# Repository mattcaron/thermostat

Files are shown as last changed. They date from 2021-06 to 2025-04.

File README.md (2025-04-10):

# The super awesome thermostat

## Introduction

Let's face it - all these thermostat products you can buy today are any or many of:

1. stupid expensive,
1. flawed in some way
1. don't do exactly what you want (see above)
1. aren't hackable
1. sell your data to some huge company

Let's address that, shall we?

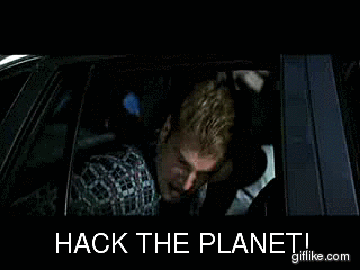
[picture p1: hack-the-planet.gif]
HACK THE PLANET!!!


## Getting started

Clone this as follows:

```shell
git clone --recursive https://github.com/mattcaron/thermostat.git
```

This will get this repo and all the submodules uses (such as the Espressif repositories).

## Components

### Thermometer puck sensors

This is intended to be pretty turnkey. Build it, flash it, configure it,
stick it on the wall. It will send COAP messages to your server (see below)
which you then consume in NodeRED (also below) and make it do what you want.

**Status:** Completed, apart from TODOs. See the `sensors` subdirectory.

**Roadmap:**

1. Hardware selection: Completed
1. Firmware: Done (v2.0.0)
   1. Console: Done
   1. Config: Done
   1. OneWire to DS18B20: Done
   1. WiFi refactor: Done
   1. ~~MQTT: Done~~
      1. Replace with COAP: Done
   1. Power saving deep sleep: Done
1. Wiring diagram: Done
   - See [./sensors/wiring_instructions/wiring_instructions.md](./sensors/wiring_instructions/wiring_instructions.md)
1. Case design: Done
   - See `./enclosures/sensor*.stl`
   - These are generated from [./enclosures/sensor_puck.scad](./enclosures/sensor_puck.scad)

**TODO:**

(May never be implemented)

1. Implement CLI command completion hinting (see iperf example code).
1. CoAP DTLS
   1. The ESP8266 library supports it.
   1. The NodeRED node-red-contrib-coap doesn't.
   1. A proxy would likely work here.
1. IPv6 support for static IPs.

**Notes:**

1. **MAKE SURE YOU DO NOT CONNECT TO BOTH USB AND BATTERIES**. Seriously - the
   batteries are going to push somewhere between 3V and 4.5V and the USB is
   going to push 5V so it's likely to try to charge the batteries and that is
   probably not going to end well. Remove the batteries, *then* plug in USB.
   This should be a pretty easy mistake to avoid since this assumes a battery
   holder with screw holes behind the batteries - in order to upgrade firmware,
   you need to take the whole thing apart, and the first step to doing that is
   pulling out the batteries.
1. When you flash the firmware:
   1. The config is retained, as it is stored in a different flash partition
      than the firmware.
   1. You need to pull out the jumper wire between D0 and RST. This connection
      is necessary for deep sleep, but messes up the automatic reset circuit
      for flashing.
   1. If the delay between plugging in USB and starting the flashing process is
      too long, the board will go to deep sleep (from which it will not actually
      wake - see above) and not flash properly. If the flashing fails, hit the
      reset button, then start the flash process again.
1. I originally implemented this using 9 bit DS18B20 resolution, but the 0.5 C
   resolution was lacking. After profiling where we were spending our time, the
   overwhelming majority of it was spent waiting to bring ip WiFi, get an IP,
   etc. Therefore, it cost us very little in terms of power to kick off a full
   resolution (12 bit) conversion, giving us 0.0625C resolution.

**Known bugs:**

(May never be implemented)

1. If you save the config at the wrong time, it can try to take down WiFi when
   it is already being brought down so the unit can go to sleep. This causes an
   ESP_ERROR_CHECK to fail (because you can't bring down something that's
   already being brought down), causing a panic reboot. Eventually, I'll get
   around to modifying it so as to check for that specific error condition and
   ignore it. Note that, when this happens, the config is saved before it
   reboots, so it's not like you lose anything. Further, this is not likely to
   occur outside of initial setup - hence why I haven't bothered to
   fix it.

#### BOM

Example links are provided for clarity, in cases where the hardware is uncommon.

##### Hardware list

You will need one of each of these items for each "puck".

1. LOLIN D1 Mini Board
   - I had used a knockoff board for the previous generation, but the LDO
     regulator used was complete garbage (quiescent current measured in
     milliAmps, not microAmps) and that led to dramatically reduced battery life.
   - <https://www.wemos.cc/en/latest/d1/d1_mini.html>
1. 3 AAA battery holder with leads
   - <https://www.amazon.com/gp/product/B0156V1JGQ>
1. DS18B20 - Get the actual Maxim one.
   - I used the genuine article here, because I tried a couple of knockoffs and
    they lacked the ability to save configuration and were less precise than the
    actual Maxim product.
      - The above is accurate, but if you run it at 12 bit resolution (the
        default), it doesn't matter, and a generic knockoff will probably work
        fine. Your mileage may vary. See `sensors/main/temperature.c` and set
        `SENSOR_CONFIG_REG_VALUE` and `MEASUREMENT_DELAY_MS` accordingly.
   - <https://www.mouser.com/ProductDetail/?qs=7H2Jq%252ByxpJKpIDCbiq4lfg%3D%3D>
1. Wire of appropriate gauge - one spool each of red and black (for power and
   ground) and another for signal (orange, yellow, blue, etc.) in 22 AWD should
   work fine here.
1. Heat shrink tubing for the above - you're going to be soldering to the ends
   of the DS18B20 sensor and you'll want to heat shrink over them to ensure you
   don't get any shorts.
   - Alternatively, if you want to do slightly less soldering, you could find a
     3 pin pigtail lead with breadboard (2.54mm) pin spacing, plug the DS18B20's
     into the plug end and solder the other end to the ESP board. But, wire is
     cheaper and I rather enjoy soldering - it lets me catch up on my Oak
     Island. Your call.

#### Enclosure

The enclosure is meant to be 3D printed. See the `enclosures` subdirectory. The
files are all generated from a single SCAD file. If you want to re-render or
modify them, feel free to do so. OpenSCAD is what I use.

However, this is not strictly necessary, because I've already exported the 3
pieces as `.stl`s. They are meant to print flat, without supports, in the
orientation in which they are presented, on an FDM printer. They should print
fine in any common 3D printing material. PLA will probably work fine, given the
limited environmental effects to which they will be exposed. I used PETG, my
rationale being that it should survive the temperature fluctuations and UV
exposure a little better than PLA, but mainly because I wanted an excuse to get
PETG printing dialed in on my printer - it's still pretty stringy, but vastly
improved versus the beginning of the project.

In addition to whatever filament you will be using, you will also need
sufficient self-tapping screws to fasten the battery holder to the lid of the
enclosure - with the screws passing through the divider. I used M3 x 12mm wood
screws, as that was the head profile for which my battery holders were made.

Please note that the holes in both the lid and divider are merely intended to be
pilot holes. Since I do not know what size screw you plan to use, I cannot
ensure the correct dimension. As such, 2 drill bits will be needed.

The first must be larger than your screw and, ideally, the same diameter as the
holes in the battery holder. The goal here is to have the screw threads *not*
engage with the plastic in either the divider or the battery holder.

The second should be the diameter of your screws sans threads - the idea being
that the self-tapping screws will cut walls into the printed standoff parts of
the lid.

Given that you will be removing some material from the walls of the standoffs so
the screws do not crack the plastic, it is necessary to ensure thick enough
walls for them to not be to thin. I recommend a minimum of 2mm thick walls when
printing the lid.

The divider is intended to ensure that the board and thermostat stay in
position, with the CPU located under the upper vent and the DS18B20 positioned
just above the lower vent. The idea here is that the CPU will heat up and the
warm air will vent out the top. Ambient air will be drawn in and over the
temperature sensor, theoretically giving a more accurate reading (and surely
more accurate than if the DS18B20 was on above the CPU, with the CPU sitting
there baking it). The horizontal protrusions into which one screws the battery
case and divider are intended to serve as a heat brake as well.

Finally, note that there are no clips on this assembly, as it is meant to be
stuck to the wall with some variety of double stick tape (I like the 3M command
strips). As such, the base is stuck to the wall and the lid, batteries, board,
etc. just pull straight off. They are held in place by gravity and a small
amount of friction. The fit is snug, but not tight. As such, mounting it on the
ceiling is not advised, as it will almost certainly work loose from the
vibrations of people walking through the building and invariably land on your
cat's head. (Don't say I didn't warn you.)

### Base station

This is not intended to be a plug and go - users are expected
to program this for their specific home layout. The idea is that, if your
sensors all report the temperature, you can define what happens using
NodeRED. For the unfamiliar, NodeRED is a programming language using drag and
drop logic blocks, with the ability to program custom logic blocks in
JavaScript. As such, it should be pretty approachable to the novice
programmer.

**Status:** Done

1. Hardware selection: Completed, see below.
   - I'm not going to do a schematic for this because it's very application
     specific.
   - In short:
     1. Get an RPi
     1. Get an appropriate number of relay boards.
     1. Wire them all together.
     1. Connect your HVAC kit.
     1. Write a NodeRed program to control it all.
1. Enclosure: Done.
   - It's slotted for a slide-in cover. I plan to make one out of
   clear acrylic, just a simple score and snap.
   - See `./enclosures/controller_base.stl` for a render.
   - This is generated from
     [./enclosures/controller_base.scad](./enclosures/controller_base.scad),
     which will almost certainly require modification unless your set up is
     exactly the same as mine.
1. Firmware: Done
   1. RPi base uses RPiOS + NodeRed + some plugins
   1. Firmware is a NodeRed program - see `controller/controller.json`.

#### BOM

Example links are provided for clarity, in cases where the hardware is uncommon.

##### Hardware list

1. Raspberry Pi 3B+
   - RPi4 would likely work with minimal modification to these
   instructions.
1. SD card
   - 32GB is fine.
1. RPi screw terminal expansion board with status LEDs
   - <https://www.amazon.com/GeeekPi-Raspberry-Terminal-Breakout-Expansion/dp/B08GKSF1MD>
   - Not strictly necessary, as one can just wire directly to the header block,
     but screw terminals ensure positive connections that won't pull out on you.
1. Some solid state relay modules
   - I bought one of
     <https://www.amazon.com/SainSmart-Channel-Duemilanove-MEGA2560-MEGA1280/dp/B00ZZVQR5Q>
     for each of my zones.
   - You can get ones with more or fewer relays as needed.
   - Note that you will need at least 3 for a common setup:
     - Fan
     - Cooling
     - Heating

     More advanced setups (for example, multistage heating and cooling) will
     require more contacts.
   - You can use mechanical relays if you like, as they are cheaper. However,
     they draw more current and will (eventually) mechanically wear out. The RPi
     3B+ GPIOs are spec-ed at max 16mA per channel, with 50mA aggregate.
       - This article from arrow explains it well:
         <https://www.arrow.com/en/research-and-events/articles/crydom-solid-state-relays-vs-electromechanical-relays>
       - Using some commonly available numbers as an example, the stated typical
         current draw for a commonly used electromechanical relay was 70mA,
         wheras it was 10mA for the SSR (though in both cases, actual measured
         current draw in situ was about an order of magnitude less).
   - Note that there is a bit of a cheat here - I assume that only one contact
     will be closed at any given time per zone - that is, only one of fan, heat,
     or cool. If this is not true, and you have enough zones, you can exceed the
     overall current rating for the board. For example, if we turn on fan and
     heat for 3 zones at the stated 10mA power consumption, we will end up at
     60mA, which is more than the allowed aggregate across all GPIO contacts.

- 24VAC to 5V buck converter
  - I used
      <https://www.amazon.com/SMAKN%C2%AE-Converter-Voltage-Supply-Waterproof/dp/B00RE6QN4U>
      soldered to the power and ground pins of a USB wire.
  - The logic here is that we can power it from the 24VAC that's readily
      available at the equipment and won't have to use an additional power brick.

##### Misc supplies and equipment

1. Stranded wire for connecting screw terminals to relays.
1. Tools - strippers, small screwdrivers, etc.
1. Some lengths of furnace wire for connecting to HVAC equipment or a zone
   controller.

## Battery notes

1. As mentioned above, use a board with a good LDO regulator. We already put the
   board into deep sleep, but the power regulator consumes power at idle and the
   less it consumes, the longer the battery will last.
2. Enable access point caching (`config set cache_ap Y`). This will cut down the
   amount of time it takes to wake from deep sleep and get wifi up, saving time
   and power. If it fails to associate with the last AP, it will fall back to
   the standard process.
3. Disable DHCP (`config set use_dhcp N`) and then set a static IP and netmask
   (`config set ip_addr XXX.XXX.XXX.XXX` `config set netmask YYY.YYY.YYY.YYY`).
   This will save several exchanges over WiFi, and those tend to consume a lot
   of power (especially while transmitting). Also saves several seconds of runtime.
4. Use the static IP of your base station in the coap URL (`config set uri
   coap://ZZZ.ZZZ.ZZZ.ZZZ/whatever`). This saves a DNS lookup which, again,
   takes time and power. Note that this only works **if you know it won't
   change**. If it might change, use its hostname.

## Security notes

### WiFi

Connecting to networks with crappy (or no) security is allowed. It's your
funeral.

### SSL

#### Sensor (COAP+DTLS)

Not yet implemented, and should be. The problem is, `node-red-contrib-coap`
doesn't support DTLS, so I need to implement some sort of proxy. Big TODO that I
actually intend to do... but haven't.

In the interim, throwing a slug on the end of the target COAP URL so people
can't poison your sensor data may help. It's a little security by obscurity, but
better than nothing. I added a -12345 in my example. I know, I know, it's the
kind of thing an idiot would have on his luggage, but it's not what I'm actually
using in production.

#### NodeRED / Webserver

This is just using the default selfsigned cert that's generated when Apache is
installed.

## License

Broadly speaking, this code is licensed under the 3-Clause BSD license. However,
it incorporates various third party modules that have their own licenses, in
which case those licenses apply. If there is ever a conflict (for example, a
derived work), then the terms of that license have precedence. See the LICENSE
file for more details.

## FAQ

### **Y U NO ZIGBEE?**

Because I have WiFi coverage all over my house, and the cost is about the same.
I will grant you that battery life would be better with Zigbee, but that's not
the only consideration in play here.

### **What's all this about your data and huge coporations?**

Maybe it's because I don't like being the product. Maybe I just read too much
cyberpunk. Maybe I just am a little paranoid. Or maybe I'm just a control freak.
Take your best guess.

### **But, half the links are to Amazon!**

Yeah, I'm a hypocrite too, what's your point?

### **How long is the battery life?**

In v1, it was about a month. This was using the old MQTT implementation, DHCP,
not caching the AP, and connecting to the base via hostname.

In v2, using COAP and all the techniques listed up in "Battery notes", a set of
3 2000mAh batteries last about 2.5 months. 2400mAh batteries push you over 3
months. Note that these need to *actually* be performing at their rated
capacities - I've gotten a lot of batteries that said 2400 or higher on the
nameplate, and they only test out to about 2000mAh.

## Acknowledgements

1. I totally cribbed battery saving techniques from
   <https://blog.sarine.nl/2020/01/01/1-year-sensor.html>
1. The above linked to <https://www.bakke.online/index.php/2017/06/24/esp8266-wifi-power-reduction-avoiding-network-scan/>
 which I also incorporated (though I just wrote to NVS, not RTC.)

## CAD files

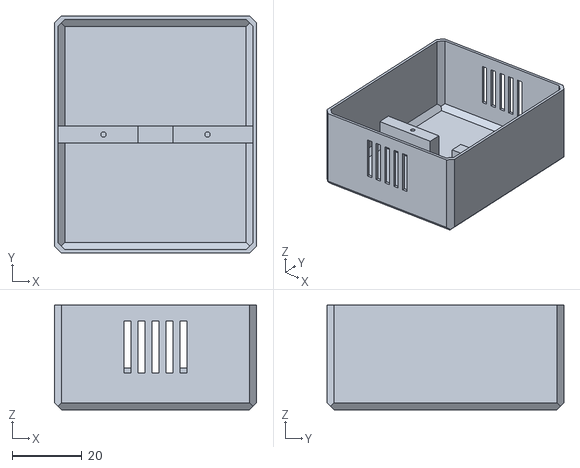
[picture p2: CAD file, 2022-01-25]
enclosures/sensor_puck_lid.stl
58.0 x 68.0 x 30.0

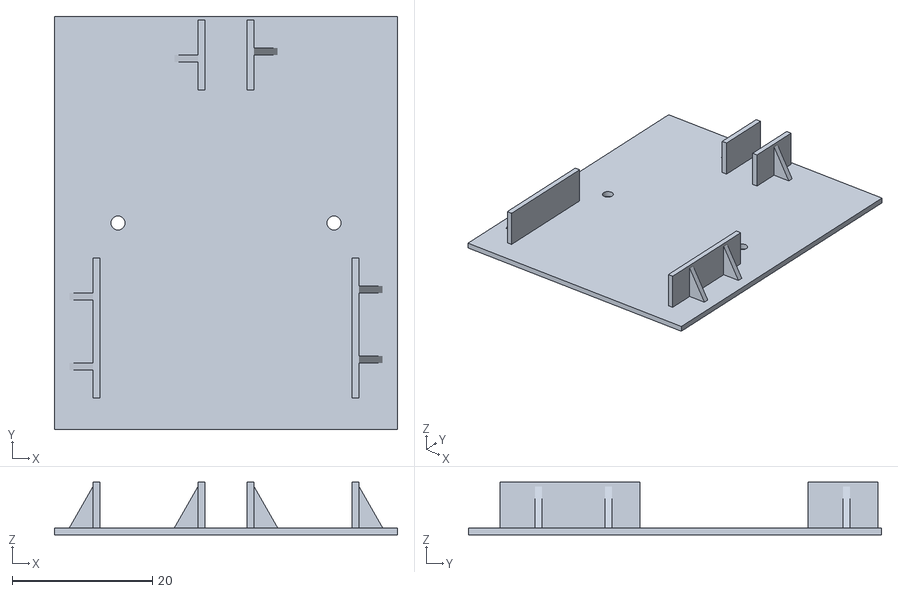
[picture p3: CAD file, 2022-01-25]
enclosures/sensor_puck_divider.stl
49.0 x 59.0 x 7.50

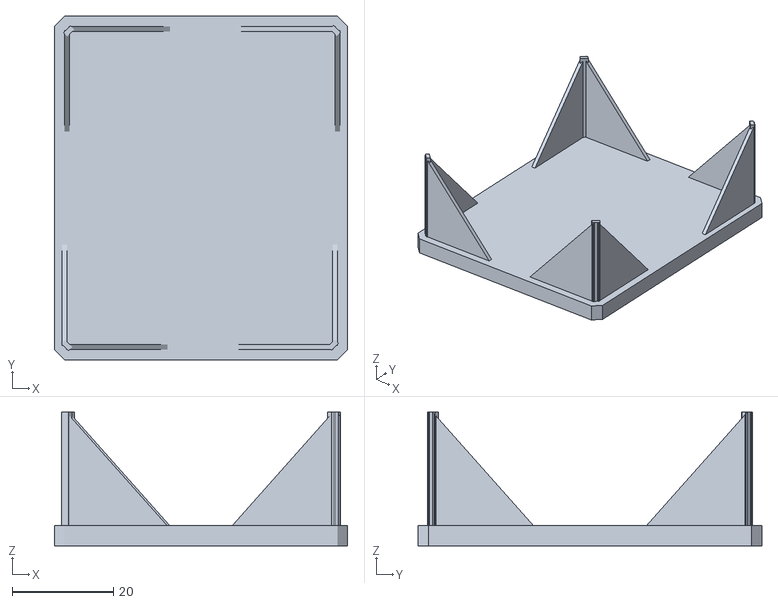
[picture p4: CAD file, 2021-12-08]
enclosures/sensor_puck_base.stl
58.0 x 68.0 x 26.5

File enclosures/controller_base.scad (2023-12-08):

include <triangles.scad>;

// Dimensions are in mm

// Fragment count. Use this many fragments to make a circle.
$fn = 360;

base_length = 180;
base_width = 180;
base_thickness = 5;
// cover holder height - this is the RPI height plus the 10mm standoffs, plus a bit
base_height = 60;

// thickness of lexan cover
lexan_thickness = 4;

// thickness of "stands" to support the above lexan cover
cover_support_thickness = 3;

// how much the angle should come out into the main base
cover_support_reinforcement = 15;

// all our standoffs are the same size
standoff_height = 10;
standoff_diameter = 5;

// screws. The hole should be large enough to not engage the threads.
screw_hole_diameter = 3;
screw_head_diameter = 5;
screw_hole_height = 1000; // more or less infinitely high.
// min thickness of the board for the screws to actually be 
// held by
board_screw_thickness = 1;

// larger screws for power converter. These are coarse thread
// self-tapping screws that are just screwed into the backer.
// This should be small enough to enage the threads,
large_screw_hole_diameter = 3.5;

// extra standoffs for the converter, because the screws I'm
// using are 13mm long and 3mm wings and a 5mm base means they would
// stick out the back. So make a 10mm standoff, measured from the bottom
// of the base (not elevated) to screw the screws into
large_screw_standoff_height = 10;

// anchor screws for mounting to the wall. This should be
// large enough to not engage the threads.
anchor_screw_hole_diameter = 6;

// SSR board volume with standoffs
module makeSSRBoard() {
    length = 73;
    width = 62;
    height = 25;
    
    union() {
        // base board volume
        cube([length, width, height]);
        
        // standoffs
        translate([5, 5, -standoff_height]) {
            cylinder(d = standoff_diameter, h = standoff_height);
        }
        
        translate([5, 56, -standoff_height]) {
            cylinder(d = standoff_diameter, h = standoff_height);
        }
        
        translate([67, 5, -standoff_height]) {
            cylinder(d = standoff_diameter, h = standoff_height);
        }
        
        translate([67, 56, -standoff_height]) {
            cylinder(d = standoff_diameter, h = standoff_height);
        }
    }
}

// this is a positive add that needs to be differenced out by whatever calls it.
module makeSSRBoardHoles() {
    // shoot some holes in it for the screws - they are infinitely tall so we can see them at the top.

    // shafts
    translate([5, 5, -screw_hole_height/2]) {
        cylinder(d = screw_hole_diameter, h = screw_hole_height);
    }
        
    translate([5, 56, -screw_hole_height/2]) {
        cylinder(d = screw_hole_diameter, h = screw_hole_height);
    }
        
    translate([67, 5, -screw_hole_height/2]) {
        cylinder(d = screw_hole_diameter, h = screw_hole_height);
    }
     
    translate([67, 56, -screw_hole_height/2]) {
        cylinder(d = screw_hole_diameter, h = screw_hole_height);
    }
    
    // heads
    translate([5, 5, -(base_thickness + board_screw_thickness + standoff_height)]) {
        cylinder(d = screw_head_diameter, h = base_thickness);
    }
    
    translate([5, 56, -(base_thickness + board_screw_thickness + standoff_height)]) {
        cylinder(d = screw_head_diameter, h = base_thickness);
    }
    
    translate([67, 5, -(base_thickness + board_screw_thickness + standoff_height)]) {
        cylinder(d = screw_head_diameter, h = base_thickness);
    }
    
    translate([67, 56, -(base_thickness + board_screw_thickness + standoff_height)]) {
        cylinder(d = screw_head_diameter, h = base_thickness);
    }
}

module makeRPI() {
    length = 88;
    width = 60;
    height = 41; // includes 15mm of space to plug into header pins and route wires
         
    union() {
        // base board volume
        cube([length, width, height]);
        
        // standoffs
        translate([3.5, 6.5, -standoff_height]) {
            cylinder(d = standoff_diameter, h = standoff_height);
        }

        translate([3.5, 55.5, -standoff_height]) {
            cylinder(d = standoff_diameter, h = standoff_height);
        }

        translate([61.5, 6.5, -standoff_height]) {
            cylinder(d = standoff_diameter, h = standoff_height);
        }

        translate([61.5, 55.5, -standoff_height]) {
            cylinder(d = standoff_diameter, h = standoff_height);
        }
    }
}

// this is a positive add that needs to be differenced out by whatever calls it.
module makeRPIBoardHoles() {
    // shoot some holes in it for the screws - they are infinitely tall so we can see them at the top.

    // shafts
    translate([3.5, 6.5, -screw_hole_height/2]) {
        cylinder(d = screw_hole_diameter, h = screw_hole_height);
    }
        
    translate([3.5, 55.5, -screw_hole_height/2]) {
        cylinder(d = screw_hole_diameter, h = screw_hole_height);
    }
        
    translate([61.5, 6.5, -screw_hole_height/2]) {
        cylinder(d = screw_hole_diameter, h = screw_hole_height);
    }
     
    translate([61.5, 55.5, -screw_hole_height/2]) {
        cylinder(d = screw_hole_diameter, h = screw_hole_height);
    }
    
    // heads
    translate([3.5, 6.5, -(base_thickness + board_screw_thickness + standoff_height)]) {
        cylinder(d = screw_head_diameter, h = base_thickness);
    }
    
    translate([3.5, 55.5, -(base_thickness + board_screw_thickness + standoff_height)]) {
        cylinder(d = screw_head_diameter, h = base_thickness);
    }
    
    translate([61.5, 6.5, -(base_thickness + board_screw_thickness + standoff_height)]) {
        cylinder(d = screw_head_diameter, h = base_thickness);
    }
    
    translate([61.5, 55.5, -(base_thickness + board_screw_thickness + standoff_height)]) {
        cylinder(d = screw_head_diameter, h = base_thickness);
    }
}

module makeConverter() {
    length = 46.5;
    width = 31.5;
    height = 18;
      
    // no standoffs, but it has "wings" with U cutouts
    // for the screws
    
    wing_width = 13;
    wing_length = 9;
    wing_height = 3.5;
    
    cutout_width = 4;
    cutout_length = 7;
    
    union() {
        // base board volume
        cube([length, width, height]);
        
        // wings
        translate([length, width/2 - wing_width/2, 0]) {
            difference() {
                cube([wing_length, wing_width, wing_height]);
                translate([wing_length - cutout_length + 0.1,
                           wing_width/2 - cutout_width/2,
                           -wing_height/2]) {
                    cube([cutout_length, cutout_width, wing_height * 2]);
                }
            }
        }
        
        translate([-wing_length, width/2 - wing_width/2, 0]) {
            difference() {
                cube([wing_length, wing_width, wing_height]);
                translate([-(wing_length - cutout_length - 1.9),
                           wing_width/2 - cutout_width/2,
                           -wing_height/2]) {
                    cube([cutout_length, cutout_width, wing_height * 2]);
                }
            }
        }
    }
}

// this is a positive add that needs to be differenced out by whatever calls it.
module makeConverterBoardHoles() {
    
    // shafts
    translate([-5, 15.75, -screw_hole_height/2]) {
        cylinder(d = large_screw_hole_diameter, h = screw_hole_height);
    }
        
    translate([52, 15.75, -screw_hole_height/2]) {
        cylinder(d = large_screw_hole_diameter, h = screw_hole_height);
    }
}

module make18B20Board() {
    length = 24.5;
    width = 21;
    height = 14.5; // includes 15mm of space to plug into header pins and route wires
    
    union() {
        // base board volume
        cube([length, width, height]);
        
        // standoffs
        translate([2.5, 2.5, -standoff_height]) {
            cylinder(d = standoff_diameter, h = base_thickness);
        }

        translate([2.5, 18, -standoff_height]) {
            cylinder(d = standoff_diameter, h = base_thickness);
        }
    }
    
}

// this is a positive add that needs to be differenced out by whatever calls it.
module make18B20BoardHoles() {
    
    // shafts
    translate([2.5, 2.5, -screw_hole_height/2]) {
        cylinder(d = screw_hole_diameter, h = screw_hole_height);
    }
        
    translate([2.5, 18, -screw_hole_height/2]) {
        cylinder(d = screw_hole_diameter, h = screw_hole_height);
    }
    
    // heads
    translate([2.5, 2.5, -(base_thickness + board_screw_thickness + standoff_height)]) {
        cylinder(d = screw_head_diameter, h = base_thickness);
    }
    
    translate([2.5, 18, -(base_thickness + board_screw_thickness + standoff_height)]) {
        cylinder(d = screw_head_diameter, h = base_thickness);
    }
}
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

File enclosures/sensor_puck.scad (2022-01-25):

include <Chamfers-for-OpenSCAD/Chamfer.scad>;
include <triangles.scad>;

// Dimensions are in mm

// Fragment count. Use this many fragments to make a circle.
$fn = 360;
delta = 0.1;

// this is the gap between the "fingers" that hold the lid on,
// and the lid itself. We want this as tight as possible, so it
// doesn't fall off, but not so tight that you rip the sensor off
// the wall trying to pull it off.
wall_gap = 0.5;

enclosure_height = 70;
enclosure_length = 60;
enclosure_lid_depth = 30;
enclosure_base_depth = 4;
enclosure_wall_thickness = 2;
enclosure_divider_thickness = 1;

// there is this much subtracted from each edge of the divider
// so that it fits inside.
enclosure_divider_delta = enclosure_wall_thickness+wall_gap+3;

hole_spacing = 26.85;

// showAssembledUnit();

showItemsForPrinting();

// Render the unit, with internal components, assembled in situ.
// Comment out bits here to see how things are and do development.
module showAssembledUnit() {
    makeComponents();
    makeEnclosureLid();
    makeEnclosureBase();
    makeEnclosureDivider();
}

module showItemsForPrinting() {
/*
    translate([0,0,14]) {
        rotate([90,-90,0]) {
            makeEnclosureBase();
        }
    }
*/

    translate([0,0,20]) {
        rotate([90,90,0]) {
            makeEnclosureLid();
        }
    }

/*
    translate([0,0,-7]) {
        rotate([90,-90,0]) {
            makeEnclosureDivider();
        }
    }
*/
}

// Make the lid of the enclosure, which contains the
// components.
module makeEnclosureLid() {
    hole_diameter = 1.5;
    
    difference() {
        // basic hollow chamfered box
        translate([-10,
                   (-enclosure_length/2)+1,
                   (-enclosure_height/2)+1]) {
    
            difference() {
                chamferCube([enclosure_lid_depth,
                            enclosure_length-enclosure_wall_thickness,
                            enclosure_height-enclosure_wall_thickness],
                            ch=2,
                            chamfers=[[1, 1, 1, 1],
                                    [0, 0, 1, 1],
                                    [0, 1, 1, 0]]);
    
                translate([-enclosure_wall_thickness,
                            enclosure_wall_thickness/2,
                            enclosure_wall_thickness/2]) {
                    chamferCube([enclosure_lid_depth,
                                enclosure_length-
                                    enclosure_wall_thickness*2,
                                enclosure_height-
                                    enclosure_wall_thickness*2],
                                ch=2,
                                chamfers=[[1, 1, 1, 1],
                                        [0, 0, 1, 1],
                                        [0, 1, 1, 0]]);
                            }
                    }
            }
           
            // vents in box
            translate([enclosure_wall_thickness,
                       0,
                       -(enclosure_height/2-delta)]) {
                cube([enclosure_lid_depth/2,2,4], center=true);
            }
            translate([enclosure_wall_thickness,
                       4,
                       -(enclosure_height/2-delta)]) {
                cube([enclosure_lid_depth/2,2,4], center=true);
            }
            translate([enclosure_wall_thickness,
                       8,
                       -(enclosure_height/2-delta)]) {
                cube([enclosure_lid_depth/2,2,4], center=true);
            }
            translate([enclosure_wall_thickness,
                       -4,
                       -(enclosure_height/2-delta)]) {
                cube([enclosure_lid_depth/2,2,4], center=true);
            }
            translate([enclosure_wall_thickness,
                       -8,
                       -(enclosure_height/2-delta)]) {
                cube([enclosure_lid_depth/2,2,4], center=true);
            }
            translate([enclosure_wall_thickness,
                       0,
                       enclosure_height/2-delta]) {
                cube([enclosure_lid_depth/2,2,4], center=true);
            }
            translate([enclosure_wall_thickness,
                       4,
                       enclosure_height/2-delta]) {
                cube([enclosure_lid_depth/2,2,4], center=true);
            }
            translate([enclosure_wall_thickness,
                       8,
                       enclosure_height/2-delta]) {
                cube([enclosure_lid_depth/2,2,4], center=true);
            }
            translate([enclosure_wall_thickness,
                       -4,
                       enclosure_height/2-delta]) {
                cube([enclosure_lid_depth/2,2,4], center=true);
            }
            translate([enclosure_wall_thickness,
                       -8,
                       enclosure_height/2-delta]) {
                cube([enclosure_lid_depth/2,2,4], center=true);
            }            

    }
  
    
    // standoffs to which we screw the battery box
    difference() {
        translate([13, 0, 0]) {
            cube([enclosure_lid_depth - 20,
                  enclosure_length - enclosure_wall_thickness,
                  5],
                  center=true);
        }
        // holes
        translate([-10,
                   -(hole_spacing/2+hole_diameter),
                   0]) {
                 rotate([90,0,90]) {
                    cylinder(d=hole_diameter, h=20);
                 }
        }
        translate([-10,
                  hole_spacing/2+hole_diameter,
                  0]) {
                rotate([90,0,90]) {
                    cylinder(d=hole_diameter, h=20);
                 }
        }
        // wiring chase
        translate([10,0,0]) {
            cube([enclosure_lid_depth + delta - 15,10,12],center=true);
        }
    }
}

// Make the divider which separates the battery holder from
// the temperature sensor and PCB
module makeEnclosureDivider() {
    hole_diameter = 2;
    translate([7.8,0,0]) {
        difference() {
            cube([enclosure_divider_thickness,
                  enclosure_length - (enclosure_divider_delta * 2),
                  enclosure_height - (enclosure_divider_delta * 2)],
                  center=true);
            
            // holes
            translate([-10, -(hole_spacing/2+hole_diameter), 0]) {
                        rotate([90,0,90]) {
                        cylinder(d=hole_diameter, h=20);
                }
            }
            translate([-10, hole_spacing/2+hole_diameter, 0]) {
                rotate([90,0,90]) {
                    cylinder(d=hole_diameter, h=20);
                }
            }
        }
        
        // add in some clips
        
        // PCB clips, to prevent lateral movement.
        // Vertical movement is limited by the standoffs and lid
        
        // left side
        makeLeftSidePCBDividerClip();
        
        translate([0,0,30]) {
            rotate([180,0,0]) {
                makeLeftSidePCBDividerClip();
            }
        }
        
        // DS18B20 clips, to prevent lateral movement.
        // Vertical movement is limited by the lid and the force
        // of the wire pushing against the leads
        makeLeftSide18B20DividerClip();
        
        translate([0,0,-48]) {
            rotate([180,0,0]) {
                makeLeftSide18B20DividerClip();
            }
        } 
    }
}

// Make the left side PCB divider clip
module makeLeftSidePCBDividerClip() {
    translate([0, -19, 5]) {
        cube([7, 1, 20]);
    }
        
    translate([0, -20, 10]) {
        rotate([180,0,0]) {
            Right_Angled_Triangle(a=4,
                                  b=7,
                                  centerXYZ=[false,true,false]);
        }
    }
        
    translate([0, -20, 20]) {
        rotate([180,0,0]) {
            Right_Angled_Triangle(a=4,
                                  b=7,
                                  centerXYZ=[false,true,false]);
        }
    }
}

// Make the left side 18B20 divider clip
module makeLeftSide18B20DividerClip() {
    translate([0, -4, -29]) {
        cube([7, 1, 10]);
    }
        
    translate([0, -5, -24]) {
        rotate([180,0,0]) {
            Right_Angled_Triangle(a=4,
                                  b=7,
                                  centerXYZ=[false,true,false]);
        }
    }
}
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

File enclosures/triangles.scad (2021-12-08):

/*
Triangles.scad
 Author: Tim Koopman
 https://github.com/tkoopman/Delta-Diamond/blob/master/OpenSCAD/Triangles.scad

         angleCA
           /|\
        a / H \ c
         /  |  \
 angleAB ------- angleBC
            b

Standard Parameters
	center: true/false
		If true same as centerXYZ = [true, true, true]

	centerXYZ: Vector of 3 true/false values [CenterX, CenterY, CenterZ]
		center must be left undef

	height: The 3D height of the Triangle. Ignored if heights defined

	heights: Vector of 3 height values heights @ [angleAB, angleBC, angleCA]
		If CenterZ is true each height will be centered individually, this means
		the shape will be different depending on CenterZ. Most times you will want
		CenterZ to be true to get the shape most people want.
*/

/* 
Triangle
	a: Length of side a
	b: Length of side b
	angle: angle at point angleAB
*/
module Triangle(
			a, b, angle, height=1, heights=undef,
			center=undef, centerXYZ=[false,false,false])
{
	// Calculate Heights at each point
	heightAB = ((heights==undef) ? height : heights[0])/2;
	heightBC = ((heights==undef) ? height : heights[1])/2;
	heightCA = ((heights==undef) ? height : heights[2])/2;
	centerZ = (center || (center==undef && centerXYZ[2]))?0:max(heightAB,heightBC,heightCA);

	// Calculate Offsets for centering
	offsetX = (center || (center==undef && centerXYZ[0]))?((cos(angle)*a)+b)/3:0;
	offsetY = (center || (center==undef && centerXYZ[1]))?(sin(angle)*a)/3:0;
	
	pointAB1 = [-offsetX,-offsetY, centerZ-heightAB];
	pointAB2 = [-offsetX,-offsetY, centerZ+heightAB];
	pointBC1 = [b-offsetX,-offsetY, centerZ-heightBC];
	pointBC2 = [b-offsetX,-offsetY, centerZ+heightBC];
	pointCA1 = [(cos(angle)*a)-offsetX,(sin(angle)*a)-offsetY, centerZ-heightCA];
	pointCA2 = [(cos(angle)*a)-offsetX,(sin(angle)*a)-offsetY, centerZ+heightCA];

	polyhedron(
		points=[	pointAB1, pointBC1, pointCA1,
					pointAB2, pointBC2, pointCA2 ],
		faces=[	
			[0, 1, 2],
			[3, 5, 4],
			[0, 3, 1],
			[1, 3, 4],
			[1, 4, 2],
			[2, 4, 5],
			[2, 5, 0],
			[0, 5, 3] ] );
}

/*
Isosceles Triangle
	Exactly 2 of the following paramaters must be defined.
	If all 3 defined H will be ignored.
	b: length of side b
	angle: angle at points angleAB & angleBC.
*/
module Isosceles_Triangle(
			b, angle, H=undef, height=1, heights=undef,
			center=undef, centerXYZ=[true, false, false])
{
	valid = 	(angle!=undef)?((angle < 90) && (b!=undef||H!=undef)) : (b!=undef&&H!=undef);
	ANGLE = (angle!=undef) ? angle : atan(H / (b/2));
	a = (b==undef)?(H/sin((180-(angle*2))/2)) : 
		 (b / cos(ANGLE))/2;
	B = (b==undef)? (cos(angle)*a)*2:b;
	if (valid)
	{
		Triangle(a=a, b=B, angle=ANGLE, height=height, heights=heights,
					center=center, centerXYZ=centerXYZ);
	} else {
		echo("Invalid Isosceles_Triangle. Must specify any 2 of b, angle and H, and if angle used angle must be less than 90");
	}
}

/*
Right Angled Triangle
	Create a Right Angled Triangle where the hypotenuse will be calculated.

       |\
      a| \
       |  \
       ----
         b
	a: length of side a
	b: length of side b
*/
module Right_Angled_Triangle(
			a, b, height=1, heights=undef,
			center=undef, centerXYZ=[false, false, false])
{
	Triangle(a=a, b=b, angle=90, height=height, heights=heights,
				center=center, centerXYZ=centerXYZ);
}

/*
Wedge
	Is same as Right Angled Triangle with 2 different heights, and rotated.
	Good for creating support structures.
*/
module Wedge(a, b, w1, w2)
{
	rotate([90,0,0])
		Right_Angled_Triangle(a, b, heights=[w1, w2, w1], centerXYZ=[false, false, true]);
}

/*
Equilateral Triangle
	Create a Equilateral Triangle.

	l: Length of all sides (a, b & c)
	H: Triangle size will be based on the this 2D height
		When using H, l is ignored.
*/
module Equilateral_Triangle(
			l=10, H=undef, height=1, heights=undef,
			center=undef, centerXYZ=[true,false,false])
{
	L = (H==undef)?l:H/sin(60);
	Triangle(a=L,b=L,angle=60,height=height, heights=heights,
				center=center, centerXYZ=centerXYZ);
}

/*
Trapezoid
	Create a Basic Trapezoid (Based on Isosceles_Triangle)

            d
          /----\
         /  |   \
     a  /   H    \ c
       /    |     \
 angle ------------ angle
            b

	b: Length of side b
	angle: Angle at points angleAB & angleBC
	H: The 2D height at which the triangle should be cut to create the trapezoid
	heights: If vector of size 3 (Standard for triangles) both cd & da will be the same height, if vector have 4 values [ab,bc,cd,da] than each point can have different heights.
*/
module Trapezoid(
			b, angle=60, H, height=1, heights=undef,
			center=undef, centerXYZ=[true,false,false])
{
	validAngle = (angle < 90);
	adX = H / tan(angle);

	// Calculate Heights at each point
	heightAB = ((heights==undef) ? height : heights[0])/2;
	heightBC = ((heights==undef) ? height : heights[1])/2;
	heightCD = ((heights==undef) ? height : heights[2])/2;
	heightDA = ((heights==undef) ? height : ((len(heights) > 3)?heights[3]:heights[2]))/2;

	// Centers
	centerX = (center || (center==undef && centerXYZ[0]))?0:b/2;
	centerY = (center || (center==undef && centerXYZ[1]))?0:H/2;
	centerZ = (center || (center==undef && centerXYZ[2]))?0:max(heightAB,heightBC,heightCD,heightDA);

	// Points
	y = H/2;
	bx = b/2;
	dx = (b-(adX*2))/2;

	pointAB1 = [centerX-bx, centerY-y, centerZ-heightAB];
	pointAB2 = [centerX-bx, centerY-y, centerZ+heightAB];
	pointBC1 = [centerX+bx, centerY-y, centerZ-heightBC];
	pointBC2 = [centerX+bx, centerY-y, centerZ+heightBC];
	pointCD1 = [centerX+dx, centerY+y, centerZ-heightCD];
	pointCD2 = [centerX+dx, centerY+y, centerZ+heightCD];
	pointDA1 = [centerX-dx, centerY+y, centerZ-heightDA];
	pointDA2 = [centerX-dx, centerY+y, centerZ+heightDA];

	validH = (adX < b/2);

	if (validAngle && validH)
	{
		polyhedron(
			points=[	pointAB1, pointBC1, pointCD1, pointDA1,
						pointAB2, pointBC2, pointCD2, pointDA2 ],
			triangles=[	
				[0, 1, 2],
				[0, 2, 3],
				[4, 6, 5],
				[4, 7, 6],
				[0, 4, 1],
				[1, 4, 5],
				[1, 5, 2],
				[2, 5, 6],
				[2, 6, 3],
				[3, 6, 7],
				[3, 7, 0],
				[0, 7, 4]	] );
	} else {
		if (!validAngle) echo("Trapezoid invalid, angle must be less than 90");
		else echo("Trapezoid invalid, H is larger than triangle");
	}
}


// Examples
// Triangle(a=5, b=15, angle=33, centerXYZ=[true,false,false]);
// translate([20,0,0]) Right_Angled_Triangle(a=5, b=20, centerXYZ=[false,true,false]);
// translate([45,0,0]) Wedge(a=5, b=20, w1=10, w2=5);
// translate([-20,0,0]) Trapezoid(b=20, angle=33, H=4, height=5, centerXYZ=[true,false,true]);
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

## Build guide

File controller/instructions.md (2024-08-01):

# Controller setup instructions

Assuming one is starting with a Raspberry Pi 3 or similar...

1. Install Raspberry Pi OS Lite on the SD card via your favorite
   method and boot up the system.

1. Make a user. From here on out, the docs will assume your user is `alice`.
   Replace as appropriate.

    * **Note:** In earlier Rasberry Pi OS builds, there was a default `pi` user
      which some software (such as Node Red) assumed would be there. In Bullseye
      and later, this seems to be the user created above, but this may not
      always be true. See <https://www.raspberrypi.com/news/raspberry-pi-bullseye-update-april-2022/>.

1. Apply updates as normal:

       sudo apt update
       sudo apt dist-upgrade

1. Set it up however else you like. For example, I disabled wifi to save power
   and because I intend to just use it wired.

1. Set up NodeRED / Apache / etc.

   1. Install necessary dependencies:

          sudo apt install nodered apache2 libapache2-mod-authnz-external

   1. Generate a PEM cert/key pair via your favorite method and put them in a
      useful place. The config below assumes they will be in `/etc/ssl/private`
      and be called `apache.pem` and `apache.key`.

   1. Create a config file akin to the following in
      `/etc/apache2/sites-available/thermostat.conf`. Make sure to replace
      things for your server, email, etc. as appropriate.

          <VirtualHost _default_:80>
              ServerName thermostat
              ServerAdmin user@domain.com

              Redirect /nodered  https://thermostat/nodered
              Redirect /editor  https://thermostat/editor

              ProxyPass / http://localhost:1880/nodered/ui/
              ProxyPassReverse / http://localhost:1880/nodered/ui/
          </VirtualHost>

          <VirtualHost _default_:443>
              ServerName stairs
              ServerAdmin matt@mattcaron.net

              SSLEngine on
              SSLCertificateFile    /etc/ssl/private/apache.pem
              SSLCertificateKeyFile /etc/ssl/private/apache.key

              # Standard SSL protocol adustments for IE
              BrowserMatch "MSIE [2-6]" \
                           nokeepalive ssl-unclean-shutdown \
                           downgrade-1.0 force-response-1.0
              BrowserMatch "MSIE [17-9]" ssl-unclean-shutdown

              AddExternalAuth pwauth /usr/sbin/pwauth
              SetExternalAuthMethod pwauth pipe

              <Location "/nodered">
                  AuthType Basic
                  AuthName "Login"
                  AuthBasicProvider external
                  AuthExternal pwauth
                  Require valid-user
              </Location>

              SSLProxyEngine On
              ProxyPreserveHost On
              ProxyRequests Off

              ProxyPass /nodered/comms  ws://localhost:1880/nodered/comms

              ProxyPass /nodered/comms http://localhost:1880/nodered/comms
              ProxyPassReverse /nodered/comms http://localhost:1880/nodered/comms

              ProxyPass /nodered http://localhost:1880/nodered
              ProxyPassReverse /nodered http://localhost:1880/nodered

              ProxyPass /editor http://localhost:1880/nodered
              ProxyPassReverse /editor http://localhost:1880/nodered

              ProxyPass / http://localhost:1880/nodered/ui/
              ProxyPassReverse / http://localhost:1880/nodered/ui/

          </VirtualHost>

   1. Edit the NodeRed config file (`/home/alice/.node-red/settings.js`), and make
      the following changes:

      1. Uncomment the `uiHost: "127.0.0.1",` so it only listens on localhost
         (the rest is handled by the Apache proxy, above).

      1. Set `httpRoot: '/nodered',`

   1. Enable the site above, disable the default one, and reload the config.

          sudo service nodered start
          sudo a2enmod ssl authnz_external proxy proxy_http proxy_wstunnel
          sudo a2ensite thermostat
          sudo a2dissite 000-default
          sudo service apache2 restart

   1. (Optional) Add some useful NodeRed things.

       **NOTE:** Do all these in the `~alice/.node-red` directory

      1. Add UI Components:

             npm install node-red-dashboard
             npm install node-red-contrib-flogger
             npm install node-red-node-email
             npm install node-red-contrib-coap

   1. Once that's all done, you'll need to restart nodered:

          sudo service nodered restart

   1. And make sure it starts on boot

          sudo systemctl enable nodered

   1. Allow for local temp sensing

      1. Add the following to `/etc/rc.local` (before the `exit`), making sure
         to set the `gpiopin` to whatever GPIO you attached any local sensors.
         Note that multiple devices can be created by repeating this command:

             dtoverlay w1-gpio gpiopin=14 pullup=0

      1. The device will be something like `/sys/bus/w1/devices/28-012062f7a914`
         * you'll need to look around and find it, each has a different ID.

      1. Add bc to make it easier to do math from the CLI

             sudo apt install bc

      1. And this shell script will read it out and print it on STDOUT so we can
         read it in to NodeRED. Make sure to change the `cat` command to the
         device attached to your system.

             #!/bin/sh

             temp_c=`cat /sys/bus/w1/devices/28-012062f7a914/temperature`
             echo "scale=1; $temp_c/1000*1.8 + 32" | bc

   1. Set up system email forwarding (assuming you want to get emails from the
      watchdog when it reboots the system):

      1. Install it:

             sudo apt install ssmtp

      1. And then configure `/etc/ssmtp/ssmtp.conf` appropriately.

   1. Enable the watchdog timer.

      This is so that, if the hardware locks up, it will get rebooted.

      1. Enable it in the devicetree.
         1. Edit `/boot/config.txt`
         1. Find the `dtparam` lines that enable `spi` and `i2c`.
         1. Add the following line:

                dtparam=watchdog=on

      1. Install the `watchdog` package:

             sudo apt install watchdog

      1. Configure it:
         1. Edit `/etc/watchdog.conf`
         1. Uncomment the following lines:

                watchdog-device         = /dev/watchdog
                max-load-1              = 24
                max-load-5              = 18
                max-load-15             = 12
                min-memory              = 1
                allocatable-memory      = 1

         1. And this one needs to be uncommented and changed:

                watchdog-timeout        = 15

         1. The rest should be fine at the defaults.

      1. Enable it:

             sudo systemctl enable watchdog

      1. Reboot

1. Make sure to give it either a static IP or a static DHCP lease and add that
   IP to your local network DNS lookup. The reason here is that the sensors need
   to be able to get to it to submit their temperature information. If they are
   using static IPs, they will connect to that IP, so it better not change. If
   you have it use a hostname, it will do a DNS lookup, and that could change,
   but if you reboot the router, then it may not end up resolving until the next
   time the controller renews its lease (unless you go reboot it). In that
   scenario, you run the risk of the sensors not being able to connect to the
   controller for however long the DHCP lease has remaining. If it's a static
   lease and associated DNS entry, however, if will keep the old IP which will
   be valid (because the DHCP server hands out the same IP every time) and the
   hostname will resolve, because it's in a static lookup table rather than
   being dynamically updated by DHCP registrations.

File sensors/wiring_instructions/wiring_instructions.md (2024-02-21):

# Sensor puck wiring instructions

## Overview

There are only 10 points which need to be soldered, so it's not tremendously
complex. Just go carefully and methodically and you'll be fine.

## Schematic

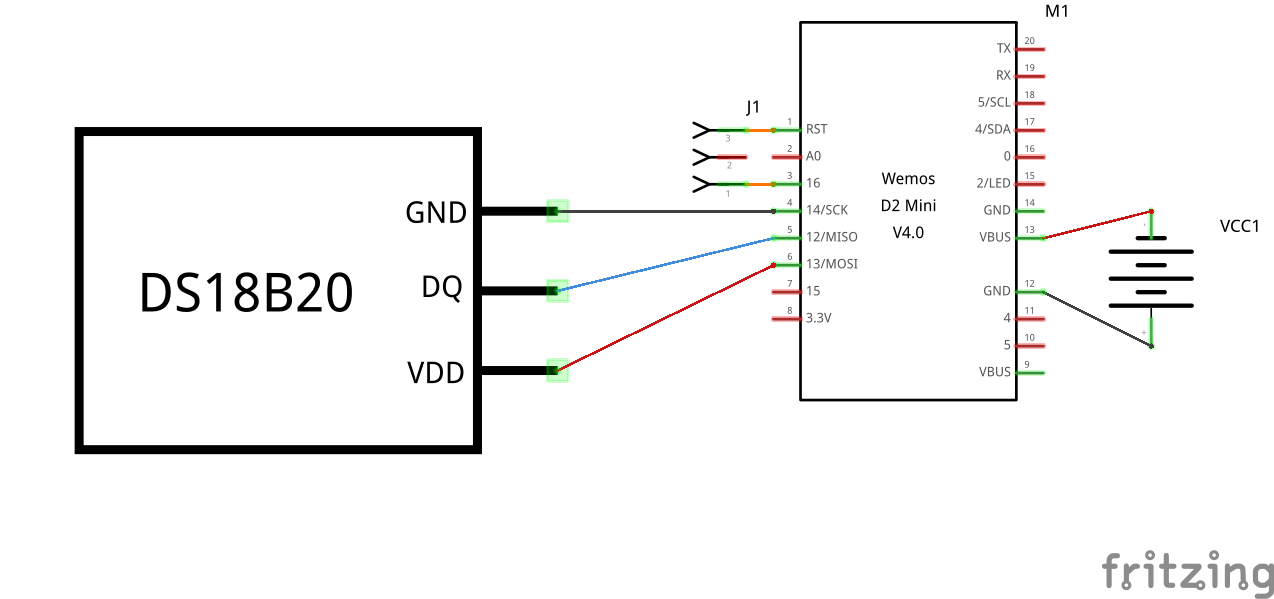
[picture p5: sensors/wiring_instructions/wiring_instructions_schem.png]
Schematic


## Render

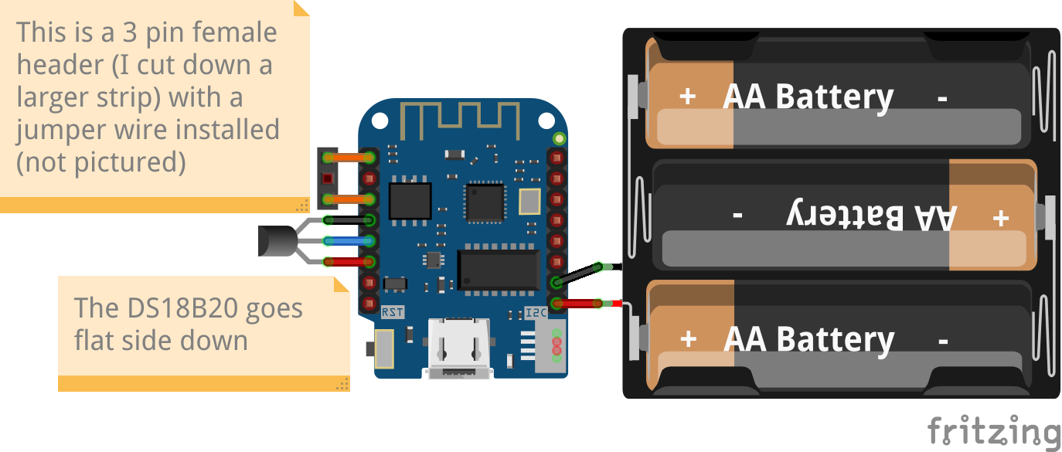
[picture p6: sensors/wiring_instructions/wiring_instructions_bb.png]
Render


## Step by step instructions

### Solder the jumper wire block

The reset line jumper wire block allows a removable connection between RST and
pin 16 which allows the low power timer output to trigger the reset line. It
would be better if these were adjacent, because then we could use a 2 pin dip
shunt but, alas, if wishes were fishes and all that. So, we use a 3 pin block
and insert a wire into it.

It needs to be removable because it's way less fiddly to flash it with the wire
removed.

Separate board and block
Board and block. The block is clipped off a larger one, and the pins are bent so
it sits flush.

Block in place in board holes
In place, but not soldered. Notice how compact it is.

Soldered together
Soldered together. A thing of beauty.

### Solder the temperature sensor

First, prep the temperature sensor with some short lead wires on it. I like to
use red for power, black for ground, and some other color for signal. Note the
positioning of ground and power - this is important. Also, to reduce the risk of
shorting, I covered the legs and joints in heat shrink.

You'll need leads of about 1 in / 2 cm in order for it to fit nicely into the
divider, but there is some wiggle room here. It's better to be slightly short
than slightly long, because the battery holder's wires can wrap around the back
quite easily.

Once you have those sorted, you can solder them to your board.

Temp sensor in position for soldering
Ready for soldering. Note that this picture is looking at the bottom of the board
(opposite of the diagrams and render), so
the flat side of the temperature sensor is facing up.

Temp sensor soldered
Here it is all soldered and in the orientation as shown in the diagram (though
rotated 180 degrees).

### Solder the battery holder and place it on the divider

From here on, it's smooth sailing - solder the battery holder positive lead to
the VBUS (5V) input (**not 3V3!!**) and the negative lead to GND (ground). Then
you arrange it on the divider as pictured below.

All laid out
Arranged and ready to go in to a holder.

### Flash and configure it

**WITHOUT BATTERIES INSTALLED**

1. Change to the `sensors` directory.

1. "dot in" the env config

       . setenv.sh

1. Connect the board to your computer.

1. Build, flash, and hit the CLI

       ./flashmonitor.sh

1. You'll get access to the CLI and you can now configure it - set your server, polling interval, etc.

1. Once you have it the way you want, you need to add a short wire between the
   two end holes of that 3 pin block we soldered on - otherwise it will go to
   sleep and not wake up.

For additional pucks, just repeat steps 3 - 6.

### Put it in the holder

From here, you install it into the puck top and affix it to the bosses with 2
screws. The board and sensor go in first, with the battery holder wrapping
around the back. Then the screws go through the battery holder into the puck and
hold it all together. This means that, once assembled, the batteries should be
accessible without having to remove any screws.

### Put the holder on the base

Once you have that assembled, you should be able to:

1. Install batteries.

2. Mount the base someplace convenient.

3. Slide the puck on to the base.

### A note on orientation

I would recommend putting the puck on the holder so that the temperature sensor
is pointed at the floor. Since heat rises, the heat from the board will go out
the vent holes in the top and draw in ambient temperature air from the bottom,
which will flow over the sensor and give you a reasonably accurate reading.

To facilitate this, I recommend marking the "top" of the puck in some fashion. I
affix a label identifying the unit to the top.

## Credits

Pretty pictures generated with [Fritzing](https://fritzing.org/).

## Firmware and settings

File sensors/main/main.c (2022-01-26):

/**
 * @file
 * Various system console commands.
 *
 * Derived from ESP8266_RTOS_SDK example
 * examples/system/console/main/console_example_main.c, which is
 * licensed as Public Domain.
 */

#include <stdio.h>
#include <string.h>
#include "esp_log.h"
#include "nvs.h"
#include "nvs_flash.h"
#include "driver/gpio.h"

#include "esp_system.h"
#include "console.h"
#include "cmd_system.h"
#include "config_storage.h"
#include "wifi.h"
#include "temperature.h"
#include "queues.h"

static const char *TAG = "main";

/**
 * Initialize nonvolatile storage.
 */
static void initialize_nvs(void)
{
    esp_err_t ret = nvs_flash_init();
    if (ret == ESP_ERR_NVS_NO_FREE_PAGES) {
        ESP_ERROR_CHECK(nvs_flash_erase());
        ret = nvs_flash_init();
    }

    ESP_ERROR_CHECK(ret);
}

/**
 * Initalize our sensor GPIOs.
 *
 * For starters, all of them are set to outputs and turned off. We'll turn
 * the comms and power on when we need them.
 */
void init_sensor_gpios(void)
{
    gpio_config_t gpios = {
        .pin_bit_mask = GPIO_Pin_12|GPIO_Pin_13|GPIO_Pin_14,
        .mode = GPIO_MODE_DEF_OUTPUT,
    };

    ESP_ERROR_CHECK(gpio_config(&gpios));

    ESP_ERROR_CHECK(gpio_set_level(GPIO_NUM_12, 0));
    ESP_ERROR_CHECK(gpio_set_level(GPIO_NUM_13, 0));
    ESP_ERROR_CHECK(gpio_set_level(GPIO_NUM_14, 0));
    ESP_ERROR_CHECK(gpio_set_pull_mode(GPIO_NUM_12, GPIO_PULLDOWN_ONLY));
    ESP_ERROR_CHECK(gpio_set_pull_mode(GPIO_NUM_13, GPIO_PULLDOWN_ONLY));
    ESP_ERROR_CHECK(gpio_set_pull_mode(GPIO_NUM_14, GPIO_PULLDOWN_ONLY));
}

/**
 * Main
 */
void app_main(void)
{
    // First thing, init our sensor GPIOs and drive to ground.
    init_sensor_gpios();

    // And then we create all our queues so they're set up for our tasks to
    // use once they are started.
    if (!create_queues()) {
        ESP_LOGE(TAG, "Error creating queues. We're screwed.");
        esp_restart();
    }

    // And get our nonvolatile storage set up.
    initialize_nvs();

    // Init our wifi task. It doesn't do anything until it gets a message, so
    // it's safe to call before we've read our config.
    start_wifi();

    // read config pre-zeroes the structure passed in, so there's no explicit
    // need to zero current_config on boot.
    if (read_config_from_nvs(&current_config)) {
        // Once we've read in our config, enable wifi.
        wifi_enable();
    }
    else {
        ESP_LOGE(TAG, "Error reading NVS config - no configuration applied.");
    }

    start_temp_polling();

    start_console();
}

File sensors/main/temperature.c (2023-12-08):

/**
 * @file
 * Temperature related functions.
 */

#include "esp_log.h"
#include "esp_sleep.h"
#include "esp_system.h"
#include <driver/gpio.h>
#include <ds18x20.h>
#include "freertos/FreeRTOS.h"
#include "freertos/task.h"

#include "priorities.h"
#include "temperature.h"
#include "config_storage.h"
#include "wifi.h"

static const char *TAG = "temperature";

#define SENSOR_GPIO GPIO_NUM_12
#define POWER_GPIO GPIO_NUM_13

/* For our config, we want to turn off the high 3 bits and leave the others
 * alone. Note that, strictly speaking, the DS18B20 only cares about bits 5
 * and 6 - bit 7 is always zero. But, some other sensors have that high bit
 * and can use it for other resolutions. But, clearing it should result in the
 * standard behavior and not bother the actual DS18B20.
 */

/* Values for the config register for various conversion precisions and
 * conversion times in ms.
 *
 * Note that various third party sensors may use these bits for other purposes;
 * if so, add them as necessary. This is only tested with the actual Dallas /
 * Maxim DS18B20.
 */
#define DS18B20_12BIT 0x7F
#define DS18B20_12BIT_TIME 750
#define DS18B20_11BIT 0x5F
#define DS18B20_11BIT_TIME 375
#define DS18B20_10BIT 0x3F
#define DS18B20_10BIT_TIME 188
#define DS18B20_9BIT  0x1F
#define DS18B20_9BIT_TIME 94

/*
 * Precision and delay selection.
 */
#define SENSOR_CONFIG_REG_VALUE DS18B20_12BIT
#define MEASUREMENT_DELAY_MS DS18B20_12BIT_TIME

/*
 * Delay in MS after sensor on to wait before doing something. This allows for
 * power to settle, capacitors to charge, etc.
 *
 * Note that anything less than 10 does nothing because portTICK_PERIOD_MS is
 * 10.
 */
#define SENSOR_ON_DELAY_MS 10

/*
 * If we are running the DS18B20 in its default mode (12 bit resolution), we
 * don't need to update the config because new parts will be set to the
 * defaults. However, if not, this needs to be set to 1 so we update the config
 * accordingly.
 */
#define CHECK_DS18B20_CONFIG 1

// The last temperature we read.
float last_temp = 0;

// Use deep sleep. Set to false for easier debugging.
bool use_deep_sleep = true;

// Pause normal operation. Defaults to false, but can be enabled via a console 
// command. Implies disabling of deep sleep.
// Note that there is no way to re-enable it; we just assume the user will 
// reboot the whole unit (and instruct them to do so).
bool paused = false;

/**
 * Turn on our sensor.
 */
static void sensor_on(void)
{
    /* Turn on the power, and set pullup mode on comms pin so the bus works.
     * The internal pullup violates the datasheet recommendations, but works,
     * and saves us an external resistor.
     */
    ESP_ERROR_CHECK(gpio_set_level(POWER_GPIO, 1));
    ESP_ERROR_CHECK(gpio_set_pull_mode(SENSOR_GPIO, GPIO_PULLUP_ONLY));

    vTaskDelay(SENSOR_ON_DELAY_MS / portTICK_PERIOD_MS);
}

/**
 * Turn off our sensor.
 */
static void sensor_off(void)
{
    /* We've now gotten the temperature, turn off the power and bus lines,
     * and pull the bus line down avoid current leakage across the pullup.
     */
    ESP_ERROR_CHECK(gpio_set_level(SENSOR_GPIO, 0));
    ESP_ERROR_CHECK(gpio_set_level(POWER_GPIO, 0));
    ESP_ERROR_CHECK(gpio_set_pull_mode(SENSOR_GPIO, GPIO_PULLDOWN_ONLY));
}

/**
 * Read the temperature.
 *
 * @param temperature [out] pointer to variable to receive the
 *                          temperature. Only valid if the function
 *                          returns true.
 *
 * @return true if the temperature read succeeded.
 * @return false if the temperature read succeeded.
 */
static bool read_temperature(float *temperature)
{
    esp_err_t ret;
    bool success = false;
    int count;

    sensor_on();

    // Start measuring. false here means don't wait.
    ret = ds18x20_measure(SENSOR_GPIO, DS18X20_ANY, false);
    count = 0;
    // occasionally we'll fail to start the conversion, so retry until
    // it succeeds or we give up.
    while (ret != ESP_OK && count < 5) {
        ret = ds18x20_measure(SENSOR_GPIO, DS18X20_ANY, false);
        ++count;
    }
    if (count > 0) {
        ESP_LOGW(TAG, "It took %d tries to start measurement.", count + 1);
    }
    if (ret != ESP_OK) {
        ESP_LOGE(TAG, "Error starting measurement: %s", esp_err_to_name(ret));
    }
    else {
        // wait for measurement to happen, adding 1 extra tick just to be
        // certain we have given ample time.
        vTaskDelay((MEASUREMENT_DELAY_MS / portTICK_PERIOD_MS) + 1);

        // Read it back.
        ret = ds18b20_read_temperature(SENSOR_GPIO, DS18X20_ANY, temperature);
        count = 0;
        // occasionally we'll get corrupt data (detectable via bad CRC)
        // so retry the read until it succeeds or we give up.
        while (ret != ESP_OK && count < 5) {
            ret = ds18b20_read_temperature(
                      SENSOR_GPIO, DS18X20_ANY, temperature);
            ++count;
        }
        if (count > 0) {
            ESP_LOGW(TAG, "It took %d tries to read the temperature.", count + 1);
        }
        if (ret == ESP_OK) {
            // We have good data, set success.
            success = true;
        }
        else {
            ESP_LOGE(TAG, "Error reading temperature: %s",
                     esp_err_to_name(ret));
        }
    }

    sensor_off();

    return success;
}
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

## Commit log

2021-05-26 Initial cut of console example.
2021-05-27 Enable SPI optimizations.
2021-05-28 Minor bracket style tweak.
2021-06-02 First pass at WiFi.
    Start, stop, print info, etc.
2021-06-09 Initialize GPIOs used for temperature sensor.
2021-06-09 Don't use nano version of newlib.
    This uses more space, but allows for printing of floats so
    temperature read produces a sane output.
2021-06-09 Implement temperature reading and console command to test it.
2021-06-30 Now that my library is fixed, remove the bus scan and just read from the one sensor.
    This will save us a few commands and thus some power.
    [temperature.c]
2021-06-30 Switch to using my fork of esp-idf-lib until it's integrated with upstream.
2021-07-02 Check and fix sensor configuration.
    [main.c, temperature.c]
2021-07-09 Switch to using a real DS18B20.
    Parasite mode, working EEPROM, totally worth it.
2021-07-10 Build in some retries to our temp read in the case of bus errors.
    [temperature.c]
2021-07-16 Add temperature unit selection, config, conversion, etc.
2021-08-03 Add temperature polling task.
2021-08-11 Add TODO and fix a comment.
    [temperature.c]
2021-08-11 Basic MQTT implementation.
    This is completely untested. It compiles, but one of my rules is not
    to check that my code works when I want to go to bed, or I'll be up
    all night. Get the code to a state where it is ready to be tested,
    then call it a night.
2021-11-03 Change flasher config to not auto reset.
    For some reason, after a month of being away from this, my dev board
    no longer wants to automatically flash. Not sure what's going on
    there. But, the workaround appears to be to tell it to flash then hold
    the flash button, press and release the reset button, then release the
    flash button, and then it's happy. But, this only works if it doesn't
    try to reset the chip when it first connects.
2021-11-03 Add code to stop a super tight infinite loop.
    If we failed to talk to the temp sensor, we'd just spin until the
    watchdog reset us. That's bad.
    [temperature.c]
2021-11-05 Remove already fixed FIXME.
    [main.c]
2021-11-05 Various WiFi bugfixes
    1.) Add status bitfield to track WiFi and MQTT connection/subscription statuses.
    2.) Use those statuses to guard against trying to send things at inappropriate times.
    3.) Make sure we have at least a basically valid config before trying to connect.
    4.) Add additional error checking for various function calls.
2021-11-05 Print MQTT status; fix up MQTT shutdown.
2021-11-05 Change flasher config to auto reset.
    Turns out, there was a bug introduced into the 5.4 kernel in later
    versions and not yet fixed on Ubuntu 20.04. Upgrading to 5.11 fixes
    it, which means I can change this back and not have to hit a button.
2021-11-12 Switch to just building in mbedTLS client support; no server support.
    We're only going to be a client. Save some space.
2021-11-12 Add buck converter.
2021-11-24 Add puck BOM.
2021-11-26 Switch smile.amazon.com links to www.amazon.com links.
2021-11-26 Change the WiFi code to not store all the config into flash.
    We already have our own WiFi to NVS storage, and I like manual control
    of the config stuff - when it gets set, and so forth. So, we'll just
    skip the writing to flash and the autoloading of the driver when it
    starts.
2021-11-26 Update SDK dependency to latest.
    I generally prefer to stick with tagged versions, but the v3.4 tagged
    version has a memory corruption error in the WiFi driver. (You can
    find it if you turn smashing detection on.) The latest version doesn't
    have it.
2021-11-26 Add a couple more status bits.
2021-12-08 Add triangles library.
    From https://www.thingiverse.com/thing:220868
    [triangles.scad]
2021-12-08 Updated polyhedron call to use "faces" instead of "triangles".
    [triangles.scad]
2021-12-08 Initial prototype for sensor puck enclosure.
    [sensor_puck.scad, sensor_puck_base.stl, sensor_puck_divider.stl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]
2022-01-15 Increase conversion time slightly to reduce failures.
    [temperature.c]
2022-01-15 Implement deep sleep disable so it doesn't reset on us when we're configuring things.
    [console.c, temperature.c]
2022-01-25 Shorter standoffs; regenerate STLs; adjust for single printing.
    [sensor_puck.scad, sensor_puck_divider.stl, sensor_puck_lid.stl]
2022-01-25 Wider wiring chase.
    Wire bundle is almost exactly 5mm, give more wiggle room to avoid wire pinching.
    [sensor_puck.scad, sensor_puck_lid.stl]
2022-01-26 Switch from parasite mode to normally powered mode.
    Parasite mode doesn't work reliably with the internal pullup.
    [main.c, temperature.c]
2022-01-26 Fix missing success path.
    [temperature.c]
2022-01-26 Add loop to retry if we get a config set failure for the DS18B20.
    [temperature.c]
2022-01-26 Fix sleep calculation; move current time get after the wait for wifi down.
    [temperature.c]
2022-02-04 Switch to production compiler config.
    1. Optimize for size, not debug.
    2. Change panic handler to reboot rather than halt.
    3. Reduce log output to just warnings and errors.
2022-02-04 Add version 1.0.0 printout.
2022-02-04 Change some status messages from info to warning / error.
    This way, they show with reduced logging.
    [temperature.c]
2022-02-04 Update README with more enclosure information and other notes.
2022-03-09 Add local temp sensor read and router instructions.
2022-03-15 Refactor config check to have the retry loop inside the function.
    This means that it will keep retrying without power cycling the
    temp sensor each time. First, it's more efficient. Second, it's more
    reliable.
2023-02-11 Add a small delay to give the sensor time to be ready after power on.
    I don't know if it's cap charging or what, but some work right away
    and some need a tick.
2023-02-12 Flip priorities of WiFi vs. temperature.
    WiFi having an event should preempt temperature sampling stuff - that
    can be less precise.
2023-05-24 Fix a bug where a too short sleep would fail to connect.
    It turns out that the guard is unecessary - we can both call connect
    when connected and, more importantly, we need to connect when we're in
    the middle of stopping the stack if we want to restart the WiFi.
    This was causing an issue in the case of doing tests where I was just
    sending temperature data without a long delay - the WiFi wouldn't
    finish coming down so it would fail to send every other packet.
    With this guard remove, we connect as normal and send data just fine.
2023-05-24 Fix a bug with our sleep interval rolling over.
    If we took too long to send data and therefore our next target waking
    time was before now, we'd subtract now from it, which means it would
    go negative and then be used to calculate the interval which would
    roll over but, since it's unsigned, we'd end up with a delay close to
    2^32 microseconds, which is still a really long time.
    This revised code now checks to see if we missed our wake up time and,
    if so, just runs our data acquisition loop again.
    Note that if this happens often, it means that the system is going to
    drain the battery very quickly because it never goes to sleep - it's
    just constantly awake waiting WiFi / data send / etc.
    Now,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
    [temperature.c]
2023-09-06 Improve UI slightly.
    1. Fix some typos.
    2. Add a `pause` command, which pauses all processing (see below).
    When testing, it's really annoying to have the console messages get
    disrupted by output from the wifi and temperature tasks. This stops
    the temperature sampling, so we don't get the output.
    [console.c, temperature.c]
2023-09-06 Add temperature sampling profiling; correct some bad math.
    1. Add counts to see how long temperature sampling takes.
    2. Add warnings when we retry various steps.
    3. In testing the WiFi stuff and trying to get the active time down, I
    realized we were spending time waiting for the temperature read,
    not WiFi, which is completely backwards, given that the sampling
    and other overhead should be on the order of 800ms. But it was
    taking 8000ms. Turns out that I forgot parens around:
    #define MEASUREMENT_DELAY_MS DS18B20_12BIT_TIME + 1
    So it was being evaluated as:
    vTaskDelay(750 + 1 / portTICK_PERIOD_MS);
    Which is, of course, 751 ticks. Since each tick is 10ms, we'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
    [temperature.c]
2023-09-06 Fix warm up delay to actually do something.
    [temperature.c]
2023-09-13 Change wifi show to emit MAC address and current IP and DNS info.
2023-12-08 Add controller enclosure.
    [controller_base.scad]
2023-12-08 Add controller example flow.
2023-12-08 Update README for v2.0.0.
    Still need to add wiring diagrams, and there are a few more features
    to implement, but it's close.
2024-02-21 Add battery life notes.
2024-02-21 Add sensor wiring diagrams.
    [wiring_instructions.fzz]
2025-04-10 Note that the sensor puck is now completed.
2026-09-21 Added overflow and condensate drain float switches.
    Overflow float is on 5, condensate drain is on 6.
    These are normally closed, so they are fed 3.3V to a pulled down
    input. Since 1 is "ok", and 0 is "tripped", a logic inversion is
    employed before storing it to global settings.
2026-09-21 Increase responsiveness for float trip messages
    Wire the float tripped messages as inputs to the zone control logic,
    triggering immediate changes on float trip.
    Required setting timestamp in the message because the zone control
    logic uses it.
2026-10-12 Adjust caching logic.
    Rather than having some convoluted logic, just delete the cache if it
    stops working.
    This means that, in the absence of wifi (say, when the power goes
    out), we'll actually give up and shut down faster.
    In the presence of wifi, we'll find a new AP and use that one.
